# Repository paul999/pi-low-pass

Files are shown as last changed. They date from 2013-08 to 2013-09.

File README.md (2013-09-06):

pi-low-pass
===========

This is a basic PCB based on the work by @CurlyMoo (https://github.com/CurlyMoo/433.92-Raspberry-Pi) to control a 433.92mhz sender/receiver with your raspberry pi.

The PCB is based on the schema by CurlyMoo, and is released under the GPLv3.

Testing
===========
The PCB, as is in the repo, has currently not tested, and can contain mistakes. Iam currently waiting for a first batch of test PCBs to make sure everything is working fine.

PCB
===========
The PCB is created with Eagle, and uses primarly SMD components to reduce the size of the PCB. As far I can see, the source eagle files are XML. If you want to contribute a patch to these PCBs, please create a pull request for your changes.

Photos of the PCB
===========
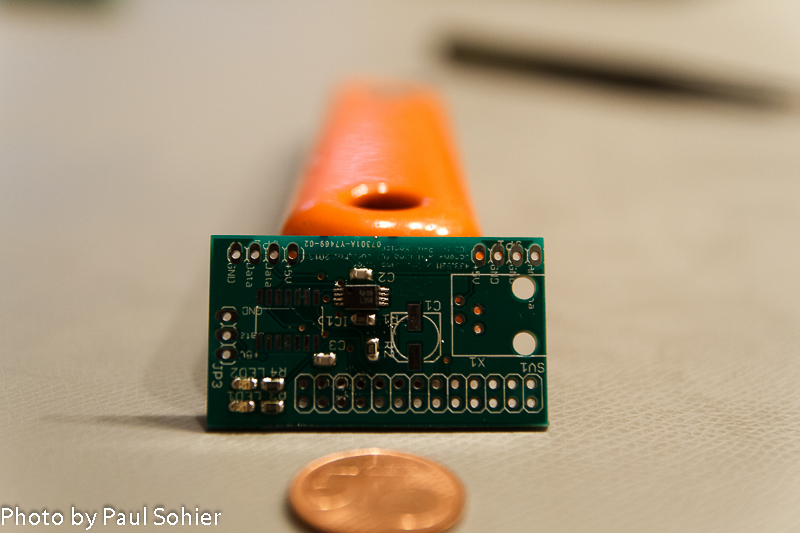
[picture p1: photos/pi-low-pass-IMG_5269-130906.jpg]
Partly soldered


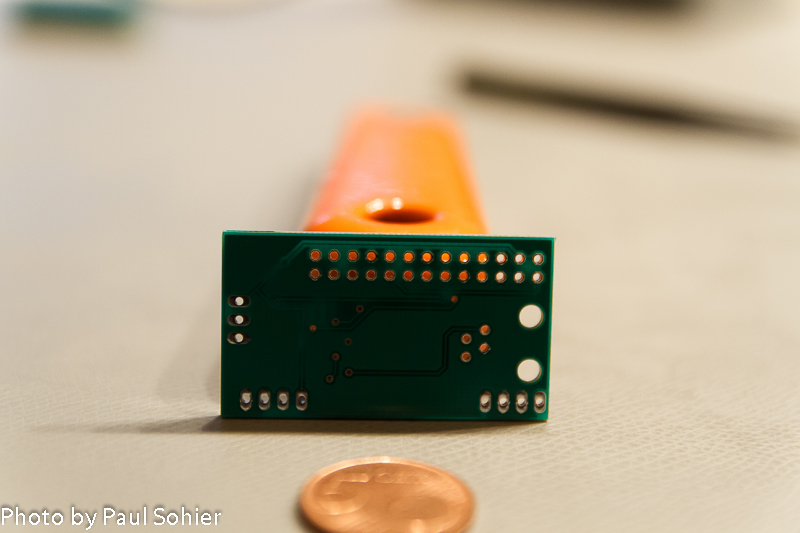
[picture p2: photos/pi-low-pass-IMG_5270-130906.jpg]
Front side


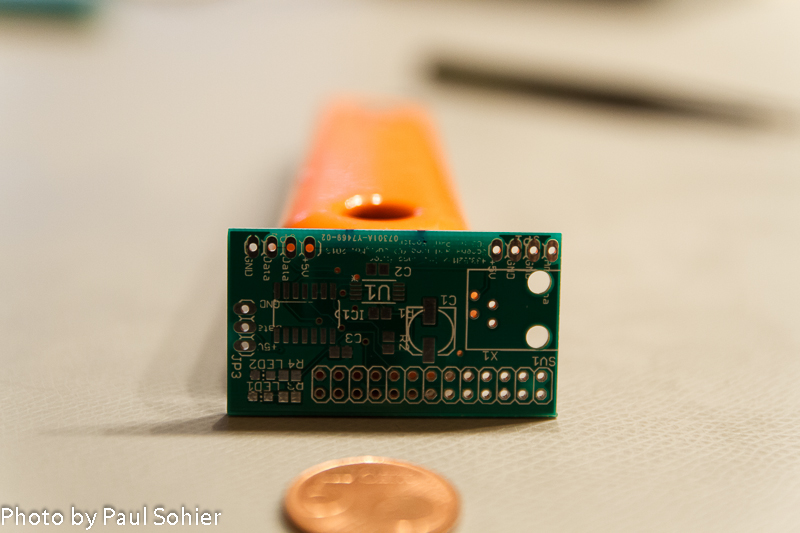
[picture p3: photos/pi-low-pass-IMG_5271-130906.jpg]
Back side


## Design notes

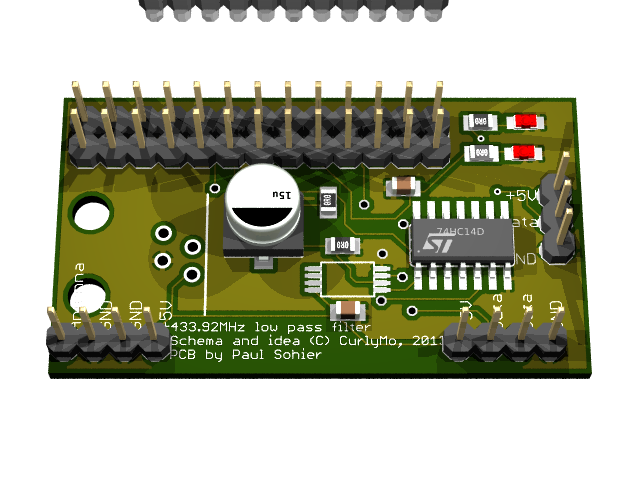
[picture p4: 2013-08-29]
3d/main_low_pass.png

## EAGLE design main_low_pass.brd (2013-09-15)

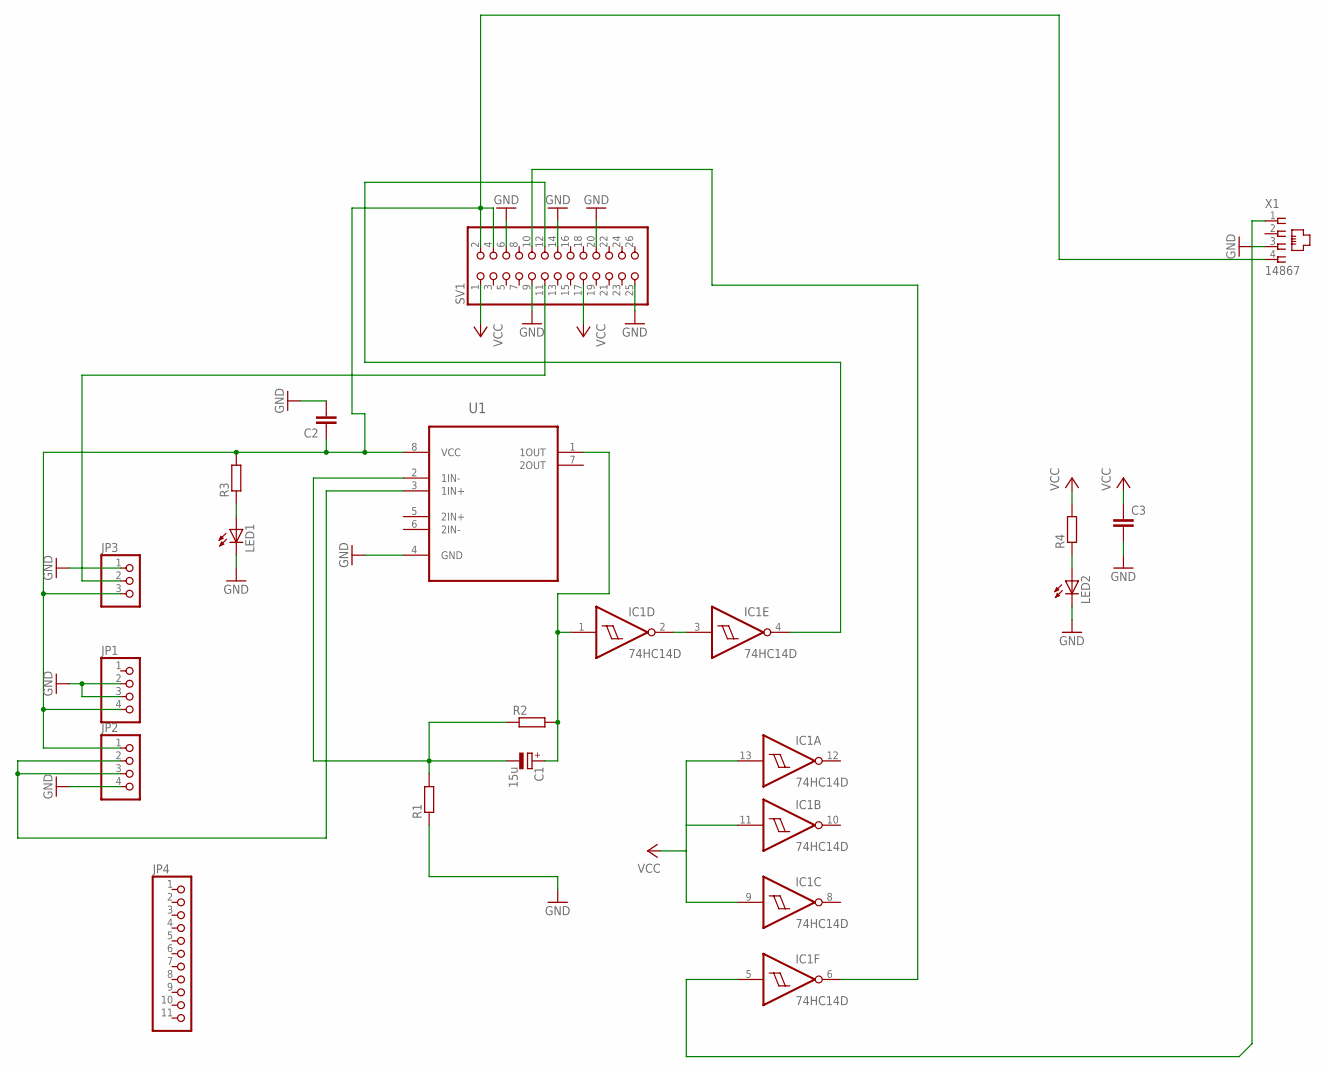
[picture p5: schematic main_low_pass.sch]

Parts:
C1: 15u; 153CLV-0605
C2, C3: C-EUC0805; C0805
IC1: 74HC14D; SO14
JP1, JP2: PINHD-1X4; 1X04
JP3: PINHD-1X3; 1X03
JP4: PINHD-1X11; 1X11
LED1, LED2: LEDCHIP-LED0805; CHIP-LED0805
R1, R2, R3, R4: R-EU_R0805; R0805
SV1: PINHD-2X13; 2X13
U1: LM358PW; SOP65P640X120-8N
X1: 14867

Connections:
GND: C2.2, C3.2, IC1.7 (GND), JP1.2, JP1.3, JP2.4, JP3.1, LED1.C, LED2.C, R1.1, SV1.6, SV1.9, SV1.14, SV1.20, SV1.25, U1.4 (GND), X1.3
unnamed: JP2.2, JP2.3, U1.3 (1IN+)
unnamed: C1.-, R1.2, R2.1, U1.2 (1IN-)
unnamed: IC1.2 (O), IC1.3 (I)
unnamed: IC1.5 (I), X1.1
unnamed: JP3.2, SV1.11
unnamed: C2.1, JP1.4, JP2.1, JP3.3, R3.2, SV1.2, SV1.4, U1.8 (VCC), X1.4
unnamed: C1.+, IC1.1 (I), R2.2, U1.1 (1OUT)
unnamed: LED1.A, R3.1
unnamed: LED2.A, R4.1
unnamed: IC1.4 (O), SV1.12
unnamed: IC1.6 (O), SV1.10
VCC: C3.1, IC1.9 (I), IC1.11 (I), IC1.13 (I), IC1.14 (VCC), R4.2, SV1.1, SV1.17

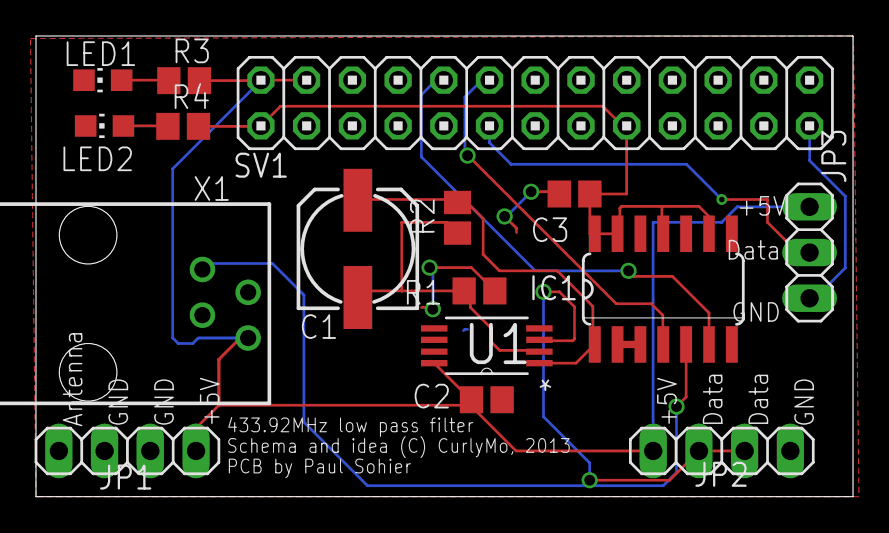
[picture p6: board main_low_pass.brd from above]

Board: 2 copper layers, 45.4 x 25.6 mm, 16 parts (0 on the bottom side), 13 nets.

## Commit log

2013-08-03 First pass of the PCB. Please note this isnt finished and should not be used yet.
    [main_low_pass.brd, main_low_pass.sch]
2013-08-03 Board update, alles moet nog nagemeten ed worden.
    [main_low_pass.GBL, main_low_pass.GBO, main_low_pass.GBP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]
2013-08-03 Some updates to the PCB, and a first list of required components.
    [main_low_pass.brd, main_low_pass.sch]
2013-08-03 SV1 verplaatst naar de zijkant ipv in het midden van het bord.
    [main_low_pass.brd]
2013-08-03 replace input connector with a headerstrip so it can be clicked on a PI, and added a second strip that copies the input from the pie.
    [main_low_pass.brd, main_low_pass.sch]
2013-08-03 Moved some stuff, tried adding a RJ1 connector as test.
    [main_low_pass.brd, main_low_pass.sch]
2013-08-04 Nieuwste revisie, connector omgedraaid zodat hij op de PI kan, RJ11 toegevoegd voor slimme meter.
    [main_low_pass.brd, main_low_pass.sch]
2013-08-29 Forgot a connection, removed outdated board files.
    [main_low_pass.GBL, main_low_pass.GBO, main_low_pass.GBP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]
2013-09-06 Some first photos of the PCB. Iam still waiting for the IC and the ElCO, so it cant be finished yet.
    [main_low_pass.GBL, main_low_pass.GBO, main_low_pass.GBP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]
2013-09-11 First set of fixes: Missed some connections to IC1
    [main_low_pass.brd]
2013-09-15 Make sure the low pass filter actually fits the pi. this change causes the board to be outside the pi, but otherwise it hits the analog out.
    [main_low_pass.brd]
